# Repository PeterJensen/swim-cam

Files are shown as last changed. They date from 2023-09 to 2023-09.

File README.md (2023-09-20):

# Swim Cam

I signed up for the [Copenhagen Open Water swim](https://copenhagenswim.com/en/) around the parliament building (Christiansborg) this year (2023), and thought it would be cool to have some image/video footage from the swimmer's POV. I was also looking for a project, so two birds with one stone. It would be much simpler to use an Insta360 or GoPro with a custom mount of some sort, but that would rob me of the chance to design a system from the ground up and write a bunch of software.

## Requirements

* 1 or 2 cameras
* Simple user interface
* Waterproof enclosure (obviously)
* Access to the recorded images/videos via WiFi Access Point
* Body mount shouldn't interfere with swim stroke/speed

I picked the ESP32-CAM as the processor/camera combo. It is inexpensive (~$6) and has no availability issues. I had worked with this board before, so there would be no gotchas. The trade-off would be a less than stellar image quality.

## User Interface

The device needs three modes; a recording mode, a WiFi access mode, and an 'idle' mode. The 'idle' mode allows for cleanly finishing writes to the SDcard, to avoid corrupting it's contents, if the power is turned off in the middle of a write operation.

The solution, I settled on, uses:
1. On/Off power switch
2. Push button
3. Led to indicate current mode

After turning on the device, it will wait 10 seconds. If the user pushes the button within those 10 seconds it will go into WiFi access mode and act as a web-server. If the user does nothing it will start recording images and saving them to the SD card.  This continues until the user pushes the button again, which brings the device into 'idle' mode. It is now safe to turn off the power switch.

The LED will indicate the mode as follows:
* **Steady On**: Power is on, waiting 10 seconds for button push
* **Slow Blink Rate**: Device is taking pictures
* **Fast Blink Rate**: Device is in WiFi hotspot mode
* **Steady Off**: Device is idle and can safely be turned off.

## Enclosure

The device should be streamlined and low profile.  I had decided to use 4x AA batteries for power, so the majority of the device volume would be taken up by batteries. It's convenient to use a widely available standard size. You can get AAs anywhere. It turned out that the device can run ~16 hours on 4 rechargeables.  Much longer on regular alkalines, I'm sure.

|||
|-|-|
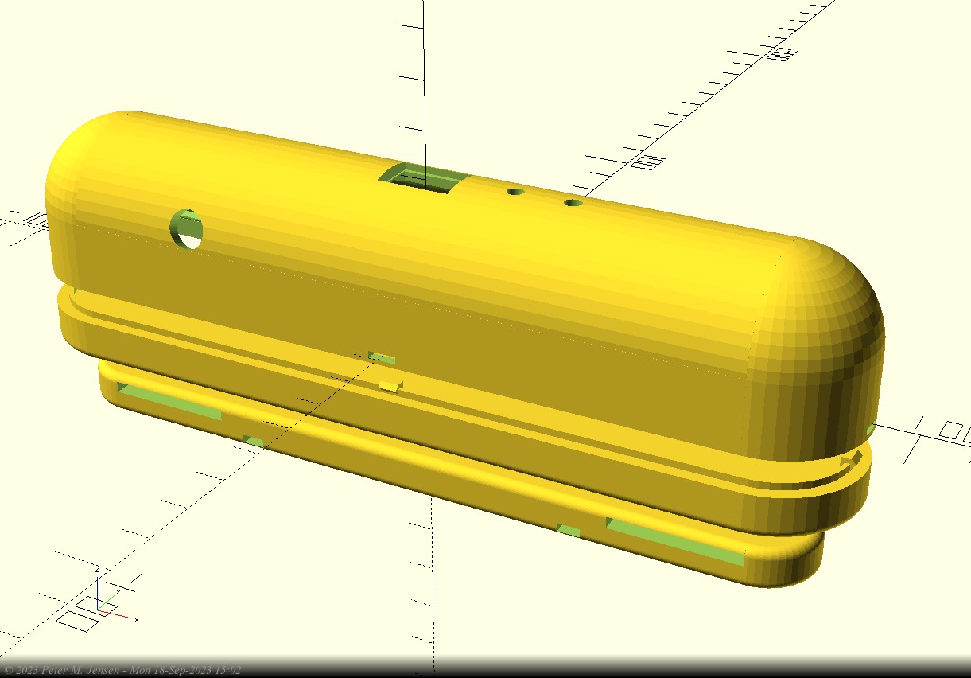
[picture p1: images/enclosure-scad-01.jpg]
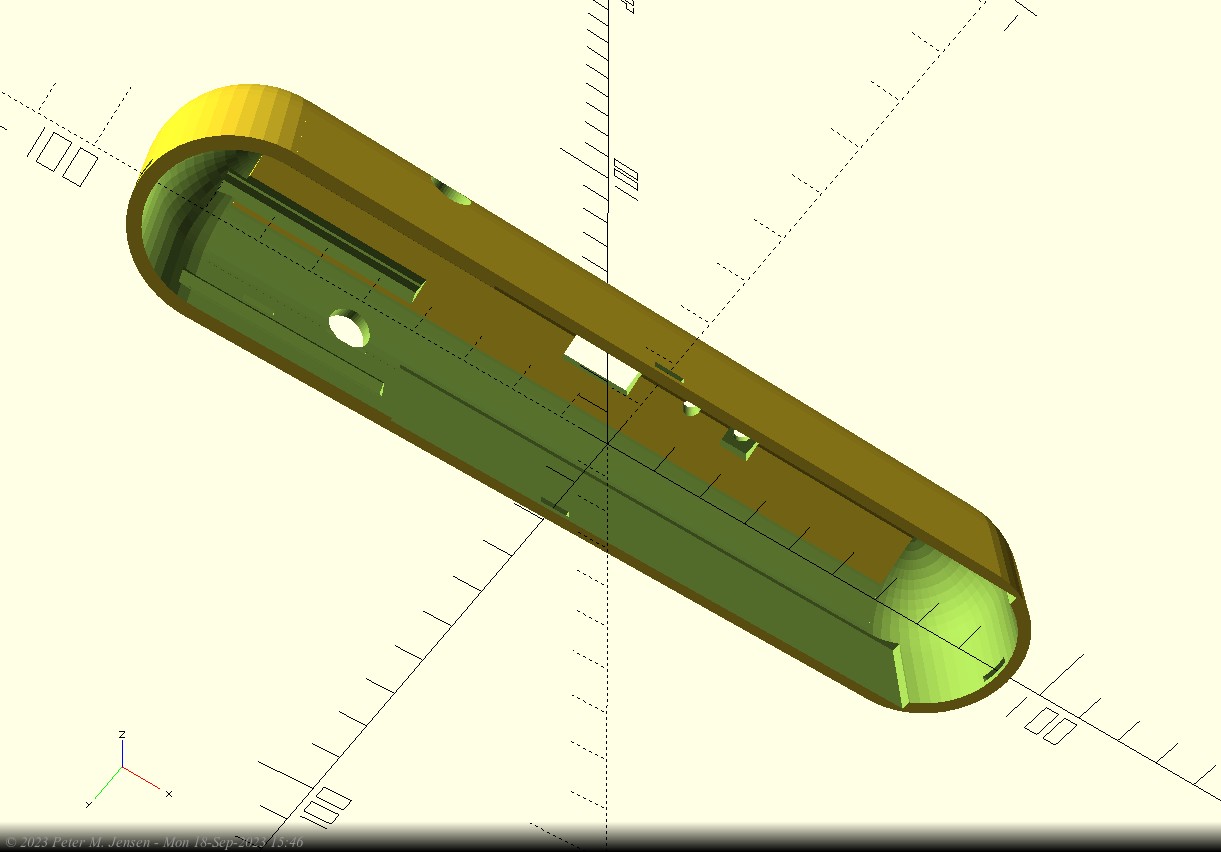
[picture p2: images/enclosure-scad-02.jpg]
|||
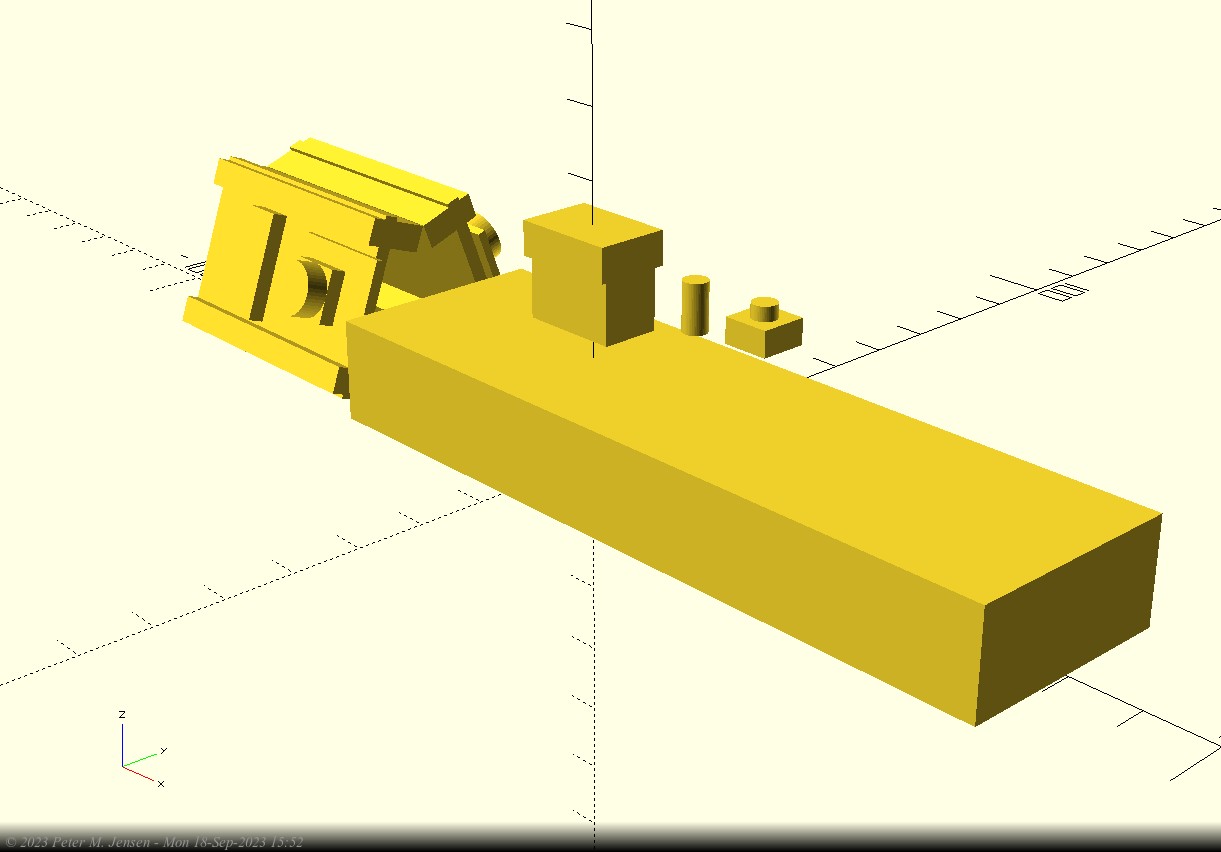
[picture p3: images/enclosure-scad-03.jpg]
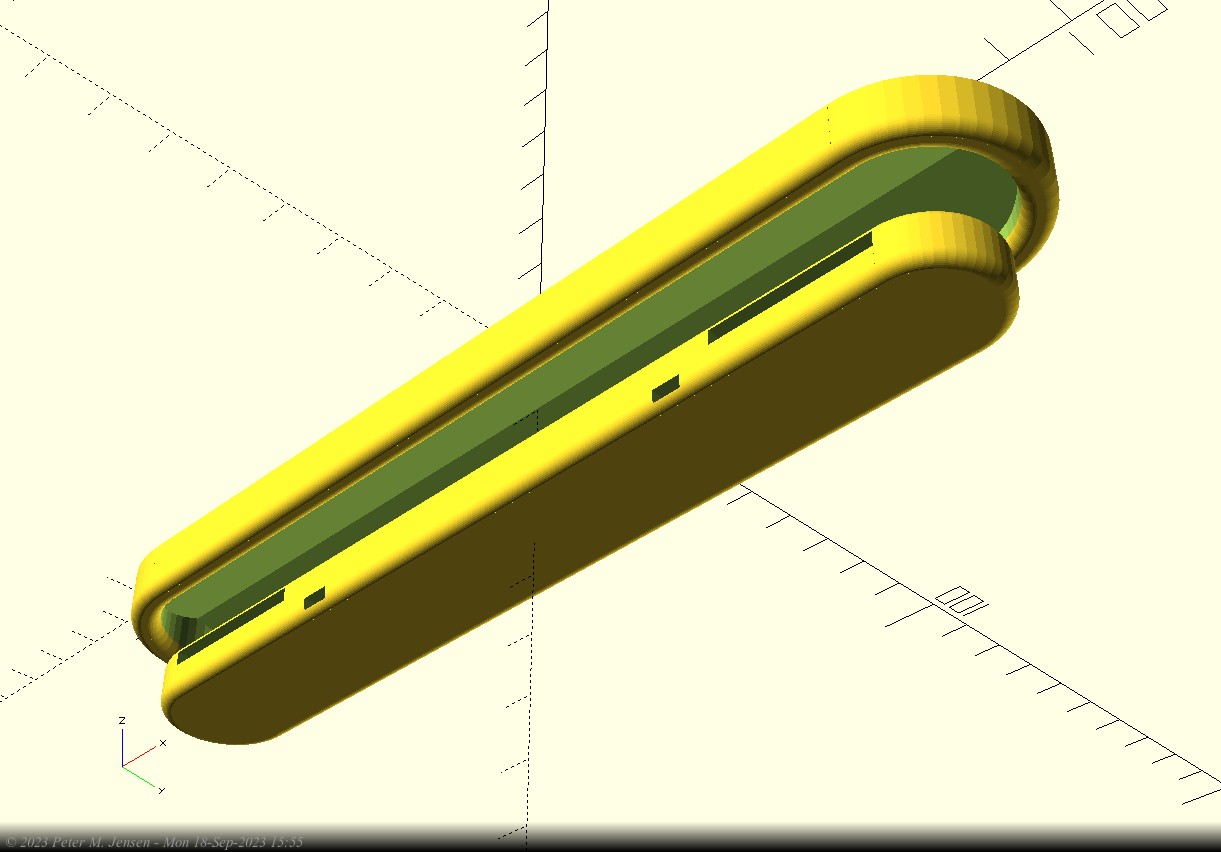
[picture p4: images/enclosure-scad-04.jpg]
|||

The enclosure consists of three separate pieces. The top part contains all the guts, the middle part is a lid for the top part. These two parts are sealed within a plastic vacuum bag.  The bottom part holds the straps and are zip tied to the top two parts. The bottom part with the straps are outside the sealed compartment.

The inside of the top part has space for two ESP32-CAM boards, and two 2xAA battery packs.

The bottom left picture shows the guts that goes inside the top part. The two slanted things to the left are two ESP32-CAM boards, the long square box is the two 2xAA battery holders. I find it useful to model the inside as well as the enclosure, so a simple difference() operation can be used to make the holes and groves in the actual enclosure. It also helps when determining the dimensions of the enclosure itself.

I used openScad for the design of the enclosure. openScad uses a scripting language, of sorts, to specify your objects. It's not much different than writing software in a regular programming language, so pretty easy to learn for a software person.

The actual device looks like this:

|||
|-|-|
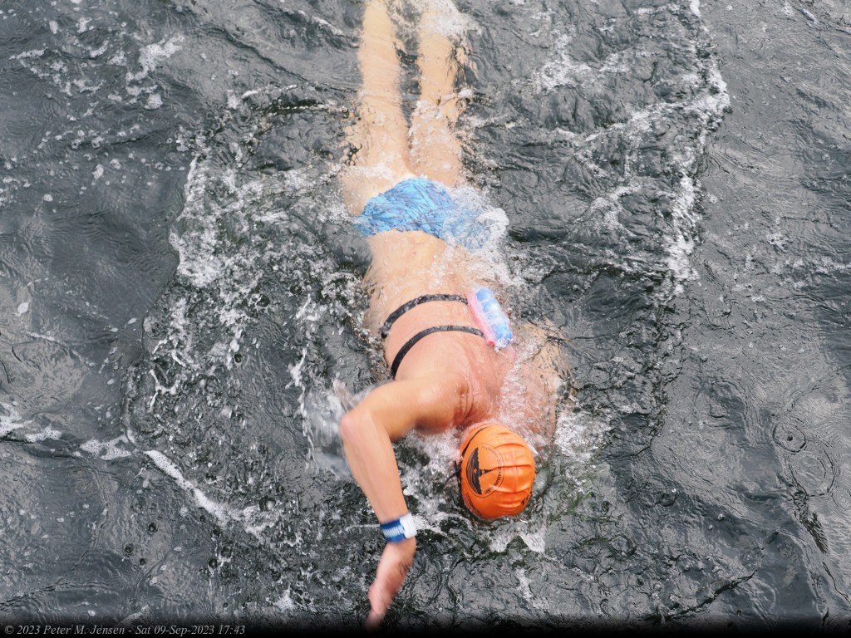
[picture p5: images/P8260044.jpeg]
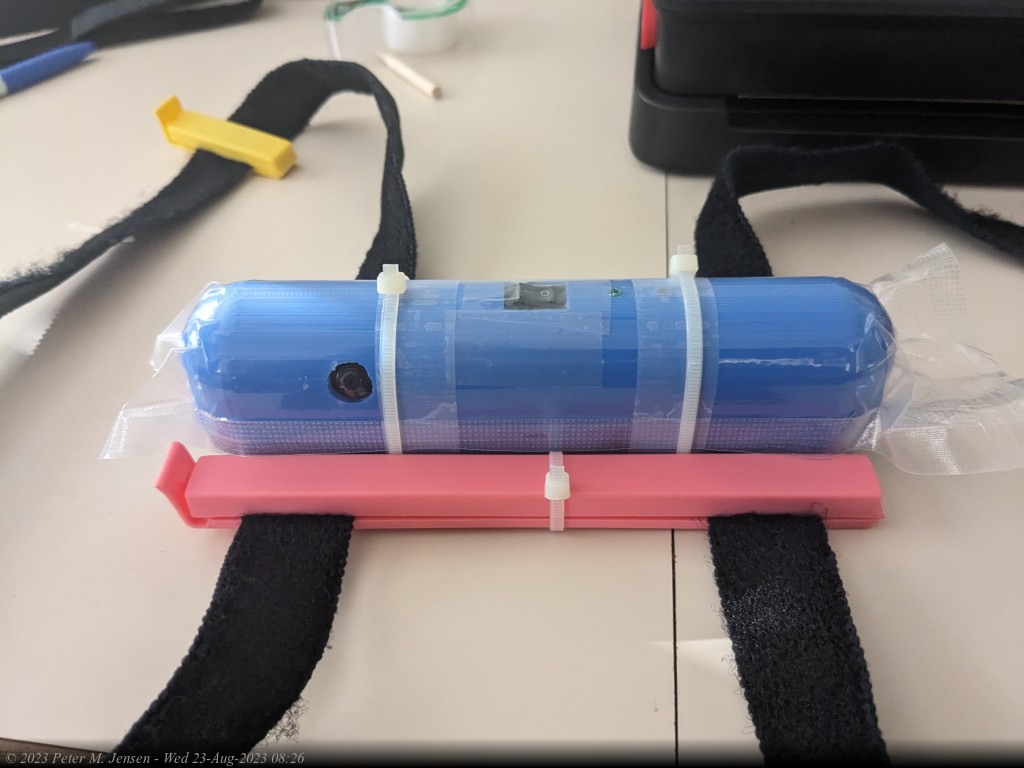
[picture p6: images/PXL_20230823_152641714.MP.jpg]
|||

The pink clips on each side are freezer bag clips. They prevent the device from sliding around.  During the 45min swim it stayed in place. The straps are velcro straps.

## ESP32-CAM

This little marvel costs about $6. For that you get:
* ESP32 MCU
* 4M PSRAM (Pseudo Static RAM). Used for frame buffers
* 2M pixel camera
* SD card slot

There's a few drawbacks though. Primarily:
* Lack of extra GPIO pins
* Processing power of the ESP32 is limiting the frame rates and sizes
* The quality of the images is less than what I would've liked
* No on-board USB/Serial chip, so an external FTD 232 device is needed. Not a big deal, and having fewer chips on the board means that less power is consumed

## Software

There are three categories of software:
* **Device**: C++ Code running on the ESP32
* **Web App**: HTML/JS single page app (SPA) for showing the images recorded on the SD card
* **Scripts for Post Processing**: A collection of Web apps and PHP scripts for extracting the good images, and presenting them as a web page

### Device Software

I used the awesome PlatformIO VS Code plugin to write this code. The project resides in the **swim-cam/** sub directory.

Images are stored on the SD card as follows:

> `GGGG/SSSS/TTTTTTTT.jpg`

**GGGG**: A 4 digit group number. Each time the device is turned on and brought into recording mode (after 10 seconds), a new group directory is created. The groups are created in sequence, i.e. 0000, 0001, 0002, etc. The highest group number holds the most recent recording.

**SSSS**: A 4 digit sub-group number. Each subgroup will hold a maximum of 100 files. The subgroups are there to prevent directories with thousands of files, since that seems to slow down access to the SD card.

**TTTTTTTT**: An 8 digit timestamp, indicating how many milli seconds have transpired since the device started recording.

### Web App Software

When the device is in WiFi hotspot mode it serves up a single page web app (SPA). The initial screen shows the available groups stored on the SD card. The last recording appears first.  After clicking on a group the images in that group can be traversed with the buttons below the image.

After connecting to the WiFi Hotspot for the camera (SWIM-CAM1), point the browser to:

> `http://192.168.4.1/`

* **>** and **<**: forward and backward one image
* **>>** and **<<**: forward and backward ten images
* **>>>** and **<<<**: forward and backward a hundred images

Here's example screenshots of the two UI screen:
|||
|-|-|
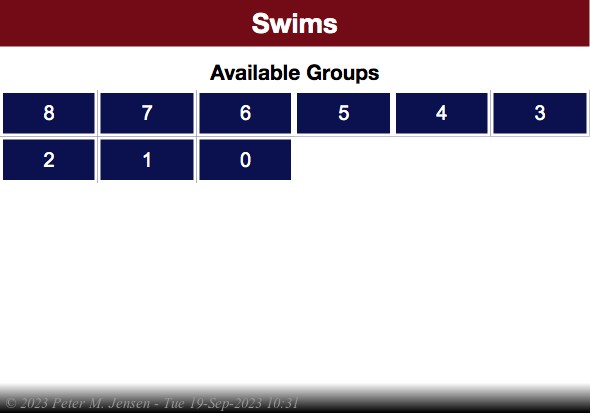
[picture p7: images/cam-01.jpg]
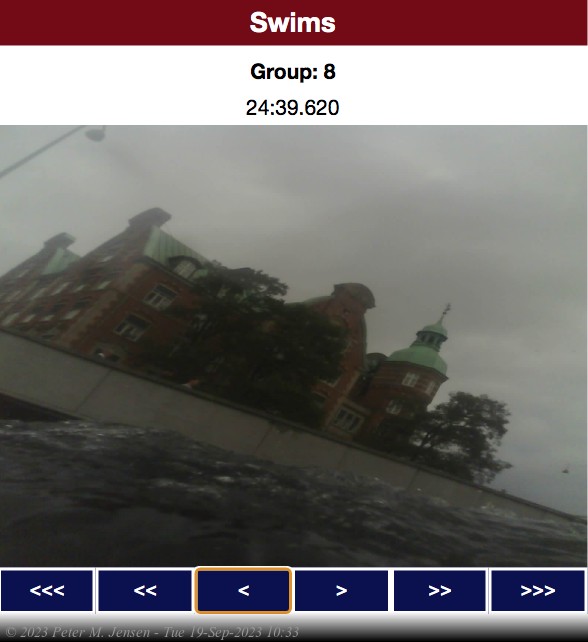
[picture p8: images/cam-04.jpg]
|||

### Scripts for Post Processing

## Actual Images from Copenhagen Swim 2023

## Post Mortem

### The Good Parts

* The enclosure didn't leak. The freezer bag vacuum packing worked like a charm
* The mounting on my back was not annoying or intrusive. I hardly noticed it. Other people did though, and it turned out to be a great conversation starter.
* User Interface and Software worked as intended. Accessing the recorded images via WiFi took a long time to initially load, when there are tens of thousands of images to show. Some re-design is needed. I had only tested it on smaller groups of images.

### The Bad Parts

* #1 issue was that very few of the in-water images had contents besides blurry images of water on them. During the 75 min of recording ~16,000 images were recorded, but only about 100 of them had contents worth looking at.
* A lot of the images weren't in focus.
* The ESP32 is only able to process (save as jpeg) about 3 full size images (1600x1200) per second. The writes to the SD card could be sped up slightly by using a 4 bit bus instead of a 1 bit one. Unfortunately, that means that there aren't enough GPIO pins available for the button and LED.

## Next Version

If I were to make a next version, I would consider:
* A better camera. Maybe the one that comes with the RaspberryPi, which is 5MP (8MP for the new one) vs. the 2MP used by the ESP32-CAM
* A more powerful CPU/Microcontroller. Probably a Raspberry Pi Pico W.
* A smaller battery. This would also make the device volume smaller. Maybe a standard 9V rechargeable instead of 4xAA.

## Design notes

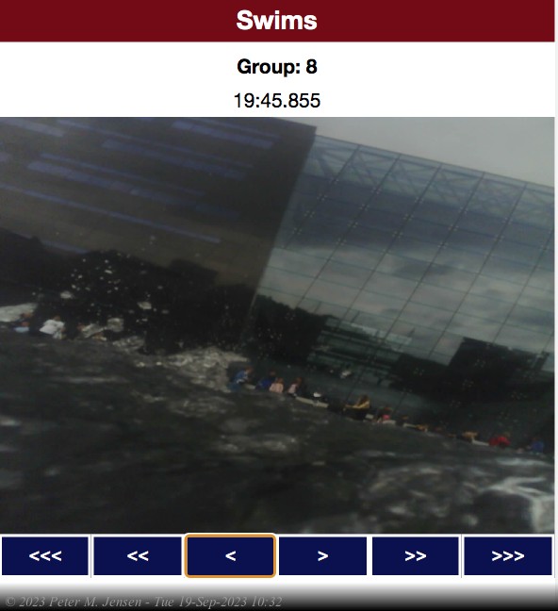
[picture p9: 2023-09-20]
images/cam-03.jpg

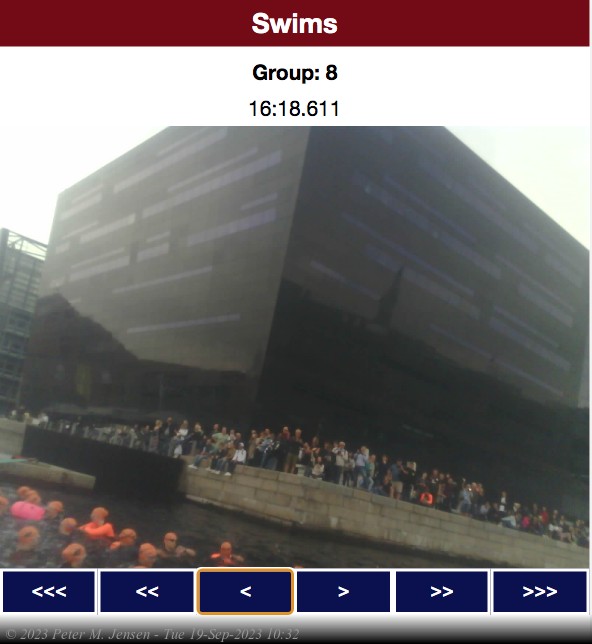
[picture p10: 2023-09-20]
images/cam-02.jpg

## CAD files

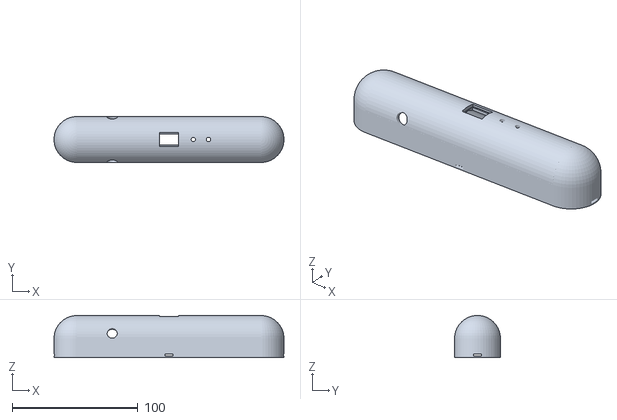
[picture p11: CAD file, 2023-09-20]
swim-cam.stl
182.9 x 36.6 x 36.6

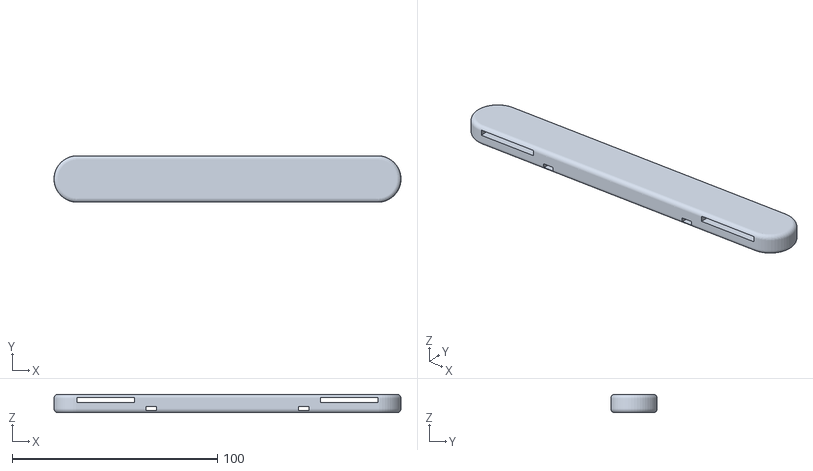
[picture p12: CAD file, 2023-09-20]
swim-cam-bar.stl
168.9 x 22.6 x 9.00

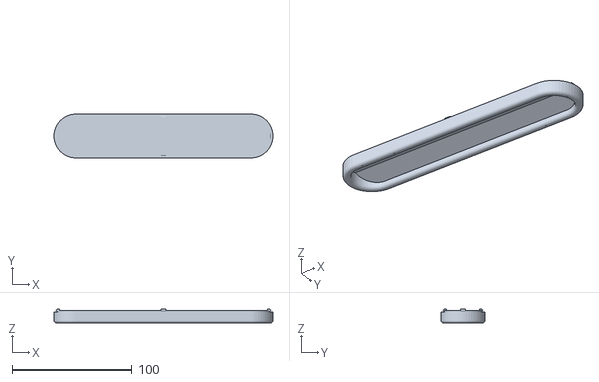
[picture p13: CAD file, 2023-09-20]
swim-cam-lid.stl
182.9 x 36.6 x 11.5

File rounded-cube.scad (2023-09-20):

// Author: Peter Jensen

module roundCut(dims, r) {
  difference() {
    translate([-1, -1, -dims.z/2-0.5])
      cube([r+1, r+1, dims.z+1]);
    translate([r, r, 0])
      cylinder(h = dims.z+1.5, r = r, center = true);
  }
}

module pillCylinder(h, r) {
  cylinder(h = h-2*r, r = r, center=true);
  translate([0, 0, h/2-r]) sphere(r = r);
  translate([0, 0, -h/2+r]) sphere(r = r);
}
  
module roundCut2(dims, r) {
  difference() {
    translate([-1, -1, -dims.z/2-0.5])
      cube([r+1, r+1, dims.z+1]);
    translate([r, r, 0])
      pillCylinder(h = dims.z, r = r);
  }
}

module cornerCut(r) {
  difference() {
    cube([r, r, r], center = true);
    translate([r/2, r/2, r/2]) sphere(r=r);
  }
}

module cornerCut4(dims, r) {
  translate([(dims.x-r)/2, (r-dims.y)/2, (dims.z-r)/2]) rotate([-90, 0, 90]) cornerCut(r);
  translate([(dims.x-r)/2, (r-dims.y)/2, (r-dims.z)/2]) rotate([0, 0, 90]) cornerCut(r);
  translate([(dims.x-r)/2, (dims.y-r)/2, (dims.z-r)/2]) rotate([-90, 0, 180]) cornerCut(r);
  translate([(dims.x-r)/2, (dims.y-r)/2, (r-dims.z)/2]) rotate([0, 0, -180]) cornerCut(r);
}  

module roundCuts(dims, edges, r) {
  echo ("roundCuts");
  if (abs(edges) != undef) {  
    translate([-dims.x/2, -dims.y/2, 0]) roundCut(dims, r);
    translate([dims.x/2, dims.y/2, 0]) rotate([0, 0, 180]) roundCut(dims, r);
    translate([dims.x/2, -dims.y/2, 0]) rotate([0, 0, 90]) roundCut(dims, r);
    translate([-dims.x/2, dims.y/2, 0]) rotate([0, 0, -90]) roundCut(dims, r);
  }
  else {
    if (edges[0]) translate([-dims.x/2, -dims.y/2, 0]) roundCut(dims, r);
    if (edges[2]) translate([dims.x/2, dims.y/2, 0]) rotate([0, 0, 180]) roundCut(dims, r);
    if (edges[1]) translate([dims.x/2, -dims.y/2, 0]) rotate([0, 0, 90]) roundCut(dims, r);
    if (edges[3]) translate([-dims.x/2, dims.y/2, 0]) rotate([0, 0, -90]) roundCut(dims, r);
  }
}

module roundedCube(dims, r, axis=[1, 1, 1]) {
  difference() {
    cube(dims, center = true);
    if (axis.x)
      rotate([0, 90, 0]) roundCuts([dims.z, dims.y, dims.x], axis.x, r);
    if (axis.y)
      rotate([90, 0, 0]) roundCuts([dims.x, dims.z, dims.y], axis.y, r);
    if (axis.z)
      roundCuts(dims, axis.z, r);
    if (axis.x && axis.y && axis.z) {
      cornerCut4(dims, r);
      rotate([0, 0, 180]) cornerCut4(dims, r);
    }
  }
}

//$fn=40;
//dims=[20,30,40];
//r = 3;

//cornerCut(dims, r);
//translate([-dims.x/2, -dims.y/2, 0]) 
//  roundCut2(dims, r);
//roundCuts(dims, 1, r);

//difference() {
//  roundedCube(dims, r, axis=[1,1,1]);
//  cornerCut4(dims, r);
//  rotate([0, 0, 180]) cornerCut4(dims, r);
//}

//pillCylinder(dims.z, r);
//cylinder(h = dims.z-2*r, r = 5, center=true);
//translate([0, 0, dims.z/2-r]) sphere(r = 5);
//translate([0, 0, -dims.z/2+r]) sphere(r = 5);

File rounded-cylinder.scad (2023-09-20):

// Author: Peter Jensen

module cutBox(d, r) {
  difference() {
    translate([0, 0, -(r)/2])
      cube([d, d, r], center = true);
    rotate_extrude() {
      translate([d/2-r, 0]) circle(r = r);
      translate([0, -r]) square([d/2-r, 2*r]);
    }
  }
}

module cutBoxRing(d, r, t) {
  difference() {
    translate([0, 0, -(r)/2])
      cube([d, d, r], center = true);
    rotate_extrude() {
      translate([d/2-r, 0]) circle(r = r);
      translate([d/2-t+r, 0]) circle(r = r);
      translate([d/2-t+r, -r]) square([t-2*r, 2*r]);
    }
  }
}
  
module roundedCylinder(d, h, r) {
  difference() {
    cylinder(d = d, h = h, center = true);
    if (r != -1)
      translate([0, 0, -h/2+r])
        cutBox(d, r);
  }
}

module roundedRing(d, h, r, t) {
  difference() {
    cylinder(d = d, h = h, center=true);
    cylinder(d = d - 2*t, h = h, center=true);
    if (r != -1)
      translate([0, 0, -h/2+r])
        cutBoxRing(d, r, t);
  }
}

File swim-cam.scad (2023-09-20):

// Author: Peter Jensen

$fn = 50;

include <rounded-cube.scad>
include <rounded-cylinder.scad>

// Dimensions

x = 0; y = 1; z = 2;

m = 0.2;

batteryDims   = [56.7+m, 32.4+m, 15.0];
//esp32Dims   = [27.1, 39.8, 1.9];
esp32Dims     = [39.8+m, 27.1+m, 1.9+m];
//esp32PinsDims = [20.0, 2.4, 8.0];
//esp32PinsDims = [20.0, 4.0, 8.0];
esp32PinsDims = [esp32Dims[x], 4.0, 9.0];
esp32SdDims   = [17.2+m, 14.6+m, 1.3];
//esp32CamDims  = [8.0+m, 8.0+m, 2.1];
esp32CamDims  = [8.0+m, 8.0+m, 2.4];
esp32CamD     = 8.0+m;
esp32CamZ     = 3.4;
//esp32CamConnDims = [5.8, 16.3, 1.9];
esp32CamConnDims = [6.0, 16.5, 2.5];

tapDims       = [4.0, 6.0, 1.5];
tapOffset     = 1.0;
switchInnerD  = 12.0;
//switchOuterD  = 13.9;
switchOuterD  = 16.0;
switchInnerZ  = 23.9;
switchOuterZ  = 7.0;
switchZ       = switchInnerZ + switchOuterZ;

esp32SdSpace  = 2.5;
shellX        = 2*batteryDims.x + esp32Dims.x + esp32SdSpace - 10.0;
shellD        = batteryDims.y + 4.0;
shellT        = 2.5;
shellXOffset  = -esp32SdSpace/2;
shellXOffset  = 0;
shellZOffset  = batteryDims.z-2;

shellRoofDims = [shellX, shellD/2 - 5.0, 2.0];
shellRoofTilt = 20;

shiftX = -3.5;
battery1Offsets   = [(batteryDims.x-shellX)/2+esp32Dims.x + esp32SdSpace + shiftX, 0, batteryDims[z]/2];
battery2Offsets   = [battery1Offsets.x + batteryDims.x, 0, batteryDims[z]/2];
esp32Tilt         = 20;
esp32LOffsets     = [(esp32Dims.x - shellX)/2 + shiftX, ( sin(esp32Tilt)-1)*batteryDims[y]/2+0.5, esp32Dims[y]/2+1];
esp32ROffsets     = [(esp32Dims.x - shellX)/2 + shiftX, (-sin(esp32Tilt)+1)*batteryDims[y]/2-0.5, esp32Dims[y]/2+1];
//esp32Pins1Offsets = [-(esp32Dims[x]-esp32PinsDims[x])/2+2.7, -(esp32Dims[y]-esp32PinsDims[y])/2+0.6, (esp32Dims[z]-esp32PinsDims[z])/2 + 0.9];
esp32Pins1Offsets = [0, -(esp32Dims[y]-esp32PinsDims[y])/2+0.6, (-esp32Dims[z]+esp32PinsDims[z])/2 - 5.0];
esp32Pins2Offsets = [esp32Pins1Offsets[x], -esp32Pins1Offsets[y], esp32Pins1Offsets[z]];
esp32SdOffsets    = [(esp32SdDims[x]-esp32Dims[x])/2-1.9, 0, (esp32Dims[z]+esp32SdDims[z])/2];
esp32CamOffsets   = [(esp32CamDims[x]-esp32Dims[x])/2+4.4, 0, (esp32CamDims[z]+esp32Dims[z])/2 + esp32SdDims[z]];


module battery1() {
  translate(battery1Offsets)
    cube(batteryDims, center = true);
}

module battery2() {
  translate(battery2Offsets)
    cube(batteryDims, center = true);
}

module esp32Cam() {
  cube(esp32CamDims, center = true);
  translate([0, 0, esp32CamDims[z]/2])
    cylinder(d = esp32CamD, h = esp32CamZ);
}
  
module esp32Base() {
  translate(esp32Pins1Offsets)
    cube(esp32PinsDims, center = true);
  translate(esp32Pins2Offsets)
    cube(esp32PinsDims, center = true);
  translate(esp32SdOffsets)
    cube(esp32SdDims, center = true);
  translate(esp32CamOffsets)
    esp32Cam();
  cube(esp32Dims, center = true);
  translate([(esp32Dims[x] - esp32CamConnDims[x])/2 - 11.5, 0, (esp32CamConnDims[z] + esp32Dims[z])/2])
    cube(esp32CamConnDims, center = true);
}

module esp32L() {
  translate(esp32LOffsets)
    rotate([-90-esp32Tilt, 0, 0])
      rotate([0, 180, 0])
        esp32Base();
}

module esp32R() {
  translate(esp32ROffsets)
    rotate([90+esp32Tilt, 0, 0])
      rotate([0, 180, 0])
        esp32Base();
}

module switchBase() {
  cylinder(d = switchInnerD, h = switchInnerZ);
  translate([0, 0, switchInnerZ])
    cylinder(d = switchOuterD, h = switchOuterZ);
}

module switch1() {
  translate([12.0, 0, 5.0])
    switchBase();
}

sm = 0.4;
switch2Dims = [6.3+sm, 6.3+sm, 3.6];
switch2D    = 3.5;
switch2Z    = 2.0;

switchSpacing = 12.0;

module switch2() {
//  translate([27.0, 0, 28.0]) {
  translate([onOffSwitchDims.x/2 + 2*switchSpacing, 0, 28.0]) {
    cube(switch2Dims, center = true);
    translate([0, 0, switch2Dims[z]/2])
      cylinder(d = switch2D, h = switch2Z);
  }
}
  
module switch2a() {
  translate([(shellX + shellD - switchZ)/2 - 0.0, 0, 22])
    rotate([0, 85, 0])
      translate([0, 0, -switchZ/2])
        switchBase();
}

module inside() {
  battery1();
  battery2();
  esp32L();
  esp32R();
  //switch1();
  switch2();
  onOffSwitch();
  led();
//  esp32Base();
}

module shellCyl() {
  difference() {
    rotate([0, 90, 0])
      translate([0, 0, -shellX/2])
        difference() {
          cylinder(d = shellD, h = shellX);
          cylinder(d = shellD-2*shellT, h = shellX);
        };
    translate([0, 0, -shellD/4])
      cube([shellX+1, shellD, shellD/2], center = true);
  }
}

module shellSphere() {
  difference() {
    sphere(d = shellD);
    sphere(d = shellD-2*shellT);
    translate([shellD/2, 0, 0])
      cube(shellD, center = true);
    translate([0, 0, -shellD/2])
      cube(shellD, center = true);
  }
}
  
module shellTop() {
  shellCyl();
  translate([-shellX/2, 0, 0])
    shellSphere();
  translate([shellX/2, 0, 0])
    rotate([0, 0, 180])
      shellSphere();
  translate([0, 0, shellD/2-7])
    shellRoof(shellRoofDims);
}

module shellCap() {
  translate([0, 0, -batteryDims[z]/2])
    difference() {
      cylinder(d = shellD, h = batteryDims[z]);
      cylinder(d = shellD - 2*shellT, h = batteryDims[z]);
      translate([shellD/2, 0, batteryDims[z]/2])
        cube([shellD, shellD, batteryDims[z]], center = true);
      translate([(tapDims[x]-shellD)/2, 0, tapDims[z]/2 + tapOffset])
        cube(tapDims, center = true);
    }
}

shellBottomOffsets = [0, 0, -batteryDims[z]/2];

module shellBottom() {
  translate(shellBottomOffsets) {
    difference() {
      cube([shellX, shellD, batteryDims[z]], center = true);
      cube([shellX, shellD - 2*shellT, batteryDims[z]], center = true);
      translate([0, (shellD - tapDims[x])/2, (tapDims[z] - batteryDims[z])/2 + tapOffset])
        rotate([0, 0, 90])
          cube(tapDims, center = true);
      translate([0, (-shellD + tapDims[x])/2, (tapDims[z] - batteryDims[z])/2 + tapOffset])
        rotate([0, 0, 90])
          cube(tapDims, center = true);
    }
    translate([-shellX/2, 0, 0])
      shellCap();
    translate([shellX/2, 0, 0])
      rotate([0, 0, 180])
        shellCap();
  }
}

module shellRoof(dims) {
  yOffset = cos(shellRoofTilt)*dims.y/2 - sin(shellRoofTilt)*dims.z/2;
  zOffset = sin(shellRoofTilt)*dims.y/2 + dims.z/2;
  translate([0, -yOffset, zOffset])
    rotate([shellRoofTilt, 0, 0])
      cube(dims, center = true);
  translate([0, yOffset, zOffset])
    rotate([-shellRoofTilt, 0, 0])
      cube(dims, center = true);
}

module shell() {
  difference() {
    translate([shellXOffset, 0, shellZOffset]) {
      shellTop();
      shellBottom();
    }
    inside();
    translate([0, 0, -batteryDims[z]])
      battery1();
    translate([0, 0, -batteryDims[z]])
      battery2();
  }
}

shellBaseDims = [shellX, shellD, 5.0];

module shellBaseShape(dims, r = -1) {
  cube(dims, center = true);
  translate([dims[x]/2, 0, 0])
    roundedCylinder(d = dims[y], h = dims[z], r = r);
  translate([-dims[x]/2, 0, 0])
    roundedCylinder(d = dims[y], h = dims[z], r = r);
}

shellBaseRimT = 1.0;

module shellBaseRimShape(dims) {
  difference() {
    shellBaseShape(dims);
    shellBaseShape([dims.x, dims.y-2*shellBaseRimT, dims.z]);
  }
}

shellBaseRimDims = [shellBaseDims[x]-0.2, shellBaseDims[y]-2*shellT-0.2, 1.5];

module shellBaseRim() {
  translate([0, 0, shellBaseRimDims[z]/2 + shellBaseDims[z]/2])
    shellBaseRimShape(shellBaseRimDims);
}

magnetD = 16.4;
magnetZ = 5.2;

module magnet() {
  cylinder(d = magnetD, h = magnetZ, center = true);
}

module magnets() {
  qx = (shellX+shellD)/16;
  translate([-6.0*qx, 0, 0])
    magnet();
  translate([-1.5*qx, 0, 0])
    magnet();
  translate([1.5*qx, 0, 0])
    magnet();
  translate([6.0*qx, 0, 0])
    magnet();
}

shellRailDims = [shellX, 5.0, shellBaseDims.z + 4.0];
//railCutDims = [shellBaseDims.x+shellD, shellBaseDims.y - 2*shellRailDims.y, shellRailDims.z];
railCutDims = [shellBaseDims.x+shellD, shellBaseDims.y - 2*shellRailDims.y, shellRailDims.z];
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

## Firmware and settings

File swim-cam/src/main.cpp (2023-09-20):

// Author: Peter Jensen

#include <Arduino.h>
#include <FS.h>
#include <SD_MMC.h>
#include <WiFi.h>
#include <driver/sdmmc_host.h>
#include <esp_heap_caps.h>
#include <soc/rtc_wdt.h>
#include "debug.h"
#include "camera.h"
#include "sdcard.h"
#include "web-ui-server.h"

struct Config {
  static constexpr const char *imageRootDir    = "/swims";
  static const uint32_t        startupDelay    = 10000;
  static constexpr const char *ssidAp          = "SWIM-CAM1";
  static constexpr const char *ipAddrAp        = "192.168.4.1";
  static const bool            setupAp         = true;
  static constexpr const char *ssidSta         = "<YOUR-SSID>";
  static constexpr const char *passwordSta     = "<YOUR-WIFI-PASSWORD>";
};

struct Pins {
  static const uint8_t pushButton = GPIO_NUM_13;
  static const uint8_t led        = GPIO_NUM_12;
  static const uint8_t ledFlash   = GPIO_NUM_4;
};

// ---------------------------------------------------------------------------
class Led {
private:
  bool       isOn;
  uint32_t   blinkRate;
  uint32_t   lastFlip;
  uint8_t    pin;
public:
  Led() : isOn(false), blinkRate(0) {}
  void init(uint8_t _pin) {
    lastFlip = millis();
    pin = _pin;
    pinMode(pin, OUTPUT);
    off();
  }
  void setBlinkRate(uint32_t rate) {
    blinkRate = rate;
  }
  void on() {
    digitalWrite(pin, HIGH);
    isOn = true;
  }
  void off() {
    digitalWrite(pin, LOW);
    isOn = false;
  }
  void flip() {
    if (isOn)
      off();
    else
      on();
    lastFlip = millis();
  }
  void update() {
    if (blinkRate > 0 && millis() > lastFlip + blinkRate)
      flip();
  }
};

// ---------------------------------------------------------------------------
class Button {
  void     (*onClickHandler)();
  uint32_t   bounceStart;
  uint8_t    pin;
  uint8_t    lastVal;
  bool       bouncing;
public:
  void init(uint8_t _pin) {
    lastVal    = HIGH;
    bouncing   = false;
    onClickHandler = nullptr;
    pin = _pin;
    pinMode(pin, INPUT_PULLUP);
  }
  void onClick(void (*handler)()) {
    onClickHandler = handler;
  }
  void update() {
    uint32_t now = millis();
    uint8_t  val = digitalRead(pin);
    if (!bouncing) {
      if (val != lastVal) {
        if (onClickHandler != nullptr && val == LOW) {
          onClickHandler();
        }
        lastVal = val;
        bounceStart = now;
        bouncing = true;
      }
    }
    else {
      if (now > bounceStart + 100) {
        bouncing = false;
      }
    }
  }
};

// ---------------------------------------------------------------------------
class State {
public:
  enum stateValue {takingPhotos, wifiHotspot, startup, idle};
  stateValue value;
private:
  uint32_t startTime;
public:
  State() : value(startup) {}
  void init() {
    startTime = millis();
  }
  bool updateTime() {
    if (value == startup) {
      uint32_t now = millis();
      if (now - startTime > Config::startupDelay) {
        value = takingPhotos;
        return true;
      }
    }
    return false;
  }
  bool updateClick() {
    if (value == startup) {
      value = wifiHotspot;
      return true;
    }
    else if (value == takingPhotos || value == wifiHotspot) {
      value = idle;
      return true;
    }
    return false;
  }
};

class Images {
  const uint32_t maxImagesInSubGroup = 100;

  String    rootDir;
  SdCard   &storage;
  String    groupDir;
  uint32_t  subGroupCount;
  String    subGroupDir;
  uint32_t  imagesInSubGroup;

  static String formatGroupDir(uint32_t num) {
    char buf[100];
    sprintf(buf, "%04d", num);
    return String(buf);
  }
  static String formatSubGroupDir(uint32_t num) {
    return formatGroupDir(num);
  }
  static String formatImageFile(uint32_t timestamp) {
    char buf[100];
    sprintf(buf, "%08d.jpg", timestamp);
    return String(buf);
  }
  static uint32_t groupDirCount;
  static void walk(const char *name, bool isDir, uint32_t size) {
    groupDirCount++;
  }
  String makeNextGroupDir() {
    groupDirCount = 0;
    storage.walkDir(rootDir, 1, walk, false);
    String nextGroupDir = rootDir + "/" + formatGroupDir(groupDirCount);
    storage.createDir(nextGroupDir);
    return nextGroupDir;
  }
  String makeSubGroupDir() {
    String nextSubGroupDir = groupDir + "/" + formatSubGroupDir(subGroupCount);
    subGroupCount += 1;
    storage.createDir(nextSubGroupDir);
    return nextSubGroupDir;
  }
public:
  Images(String rootDir, SdCard &sdCard) : rootDir(rootDir), storage(sdCard) {}
  void init() {
    subGroupCount = 0;
    groupDir = makeNextGroupDir();
    subGroupDir = makeSubGroupDir();
    imagesInSubGroup = 0;
  }  
  void addImage(uint32_t timeStamp, uint8_t *data, uint32_t dataLen) {
    if (imagesInSubGroup >= maxImagesInSubGroup) {
      subGroupDir = makeSubGroupDir();
      imagesInSubGroup = 0;
    }
    String imageFile = subGroupDir + "/" + formatImageFile(timeStamp);
    storage.createFile(imageFile, data, dataLen);
    imagesInSubGroup += 1;
  }
};
uint32_t Images::groupDirCount;

Button      button;
State       state;
SdCard      sdCard(SD_MMC);
Led         led;
Images      images(Config::imageRootDir, sdCard);
Camera      camera;
WebUiServer server(sdCard, Config::imageRootDir);

void removeZeroSize(const char *name, bool isDir, uint32_t size) {
  if (!isDir && size == 0) {
    DEBUG_PRINTF("Removing: %s\n", name);
    sdCard.removeFile(name);
  }
}

void updateLed() {
  switch (state.value) {
    case State::startup:
      led.setBlinkRate(0);
      led.on();
      break;
    case State::takingPhotos:
      led.setBlinkRate(500);
      break;
    case State::wifiHotspot:
      led.setBlinkRate(100);
      break;
    case State::idle:
      led.setBlinkRate(0);
      led.off();
      break;
  }
}

void click() {
  DEBUG_PRINTF("Button Clicked\n");
  bool change = state.updateClick();
  if (change) {
    DEBUG_PRINTF("New state after updateClick: %d\n", state.value);
    updateLed();
  }
}

void setup() {
  DEBUG_INIT();
  WRITE_PERI_REG(RTC_CNTL_BROWN_OUT_REG, 0);
  pinMode(Pins::ledFlash, OUTPUT);
  digitalWrite(Pins::ledFlash, LOW);
  led.init(Pins::led);
  led.on();
  button.init(Pins::pushButton);
  button.onClick(click);
  state.init();
}

uint32_t firstCaptureTime;
bool     hasFinishedCapturing = false;
bool     serverStarted        = false;
bool     serverStopped        = false;

void loop() {
  led.update();
  button.update();
  bool change = state.updateTime();
  if (change) {
    DEBUG_PRINTF("New state after updateTime: %d\n", state.value);
    updateLed();
  }
  switch (state.value) {
    case State::startup:
      break;
    case State::takingPhotos: {
      if (change) {
        camera.init();
        camera.dumpStatus();
        sdCard.begin();
        images.init();
        firstCaptureTime = millis();
      }
      uint8_t *buf;
      uint32_t len;
      uint32_t captureTime = millis();
      camera.capture(&buf, &len);
      images.addImage(captureTime - firstCaptureTime, buf, len);
      camera.captureRelease();
      break;
    }
    case State::wifiHotspot:
      if (!serverStarted) {
        if (Config::setupAp) {
          IPAddress ipAddr;
          ipAddr.fromString(Config::ipAddrAp);
          serverStarted = server.startAp(Config::ssidAp, ipAddr);
        }
        else
          serverStarted = server.startSta(Config::ssidSta, Config::passwordSta);
        server.startServer();
      }
      break;
    case State::idle:
      if (!hasFinishedCapturing) {
        //sdCard.walkDir(Config::imageRootDir, 3);
        sdCard.end();
        hasFinishedCapturing = true;
      }
      if (!serverStopped && serverStarted) {
        server.stopServer();
        serverStopped = true;
      }
      break;
  }
}

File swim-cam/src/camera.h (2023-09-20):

// Author: Peter Jensen

#ifndef _CAMERA_H
#define _CAMERA_H
#include <esp_camera.h>
#include "debug.h"

#define PWDN_GPIO_NUM     32
#define RESET_GPIO_NUM    -1
#define XCLK_GPIO_NUM      0
#define SIOD_GPIO_NUM     26
#define SIOC_GPIO_NUM     27

#define Y9_GPIO_NUM       35
#define Y8_GPIO_NUM       34
#define Y7_GPIO_NUM       39
#define Y6_GPIO_NUM       36
#define Y5_GPIO_NUM       21
#define Y4_GPIO_NUM       19
#define Y3_GPIO_NUM       18
#define Y2_GPIO_NUM        5
#define VSYNC_GPIO_NUM    25
#define HREF_GPIO_NUM     23
#define PCLK_GPIO_NUM     22

#define LED_GPIO_NUM      4

static camera_config_t cameraConfig = {
  .pin_pwdn = PWDN_GPIO_NUM,
  .pin_reset = RESET_GPIO_NUM,
  .pin_xclk = XCLK_GPIO_NUM,
  .pin_sccb_sda = SIOD_GPIO_NUM,
  .pin_sccb_scl = SIOC_GPIO_NUM,
  .pin_d7 = Y9_GPIO_NUM,
  .pin_d6 = Y8_GPIO_NUM,
  .pin_d5 = Y7_GPIO_NUM,
  .pin_d4 = Y6_GPIO_NUM,
  .pin_d3 = Y5_GPIO_NUM,
  .pin_d2 = Y4_GPIO_NUM,
  .pin_d1 = Y3_GPIO_NUM,
  .pin_d0 = Y2_GPIO_NUM,
  .pin_vsync = VSYNC_GPIO_NUM,
  .pin_href = HREF_GPIO_NUM,
  .pin_pclk = PCLK_GPIO_NUM,
  .xclk_freq_hz = 20000000,
  .ledc_timer = LEDC_TIMER_0,
  .ledc_channel = LEDC_CHANNEL_0,
  .pixel_format = PIXFORMAT_JPEG,
  .frame_size = FRAMESIZE_UXGA,
  .jpeg_quality = 10,
  .fb_count = 2,
  .fb_location = CAMERA_FB_IN_PSRAM,
  .grab_mode = CAMERA_GRAB_LATEST,
  .sccb_i2c_port = -1 // Not used because pin_sccb_sda != -1
};

class Camera {
  camera_fb_t *fb = nullptr;
public:
  bool init() {
    esp_err_t err = esp_camera_init(&cameraConfig);
    if (err != ESP_OK) {
      DEBUG_PRINTF("Camera: Init failed with error 0x%x\n", err);
      return false;
    }
    sensor_t *s = esp_camera_sensor_get();
    s->set_aec2(s, 1);
    pinMode(LED_GPIO_NUM, OUTPUT);
    digitalWrite(LED_GPIO_NUM, LOW);

    // warm up the camera
    uint8_t  *buf;
    uint32_t  len;
    for (uint32_t i = 0; i < 5; i++) {
      capture(&buf, &len);
      captureRelease();
    }
    delay(1000);
    for (uint32_t i = 0; i < 5; i++) {
      capture(&buf, &len);
      captureRelease();
    }
    return true;
  }
  bool capture(uint8_t **buf, uint32_t *len) {
    if (fb != nullptr) {
      DEBUG_PRINTF("Camera: Last capture not released\n");
      return false;
    }
    fb  = esp_camera_fb_get();
    if (!fb) {
      DEBUG_PRINTF("Camera: Capture fail\n");
      return false;
    }
    *buf = fb->buf;
    *len = fb->len;
    return true;
  }

  void captureRelease() {
    esp_camera_fb_return(fb);
    fb = nullptr;
  }

  void dumpStatus() {
    sensor_t        *s = esp_camera_sensor_get();
    camera_status_t *status = &(s->status);
    DEBUG_PRINTF("xclk:           %u\n", s->xclk_freq_hz/1000000);
    DEBUG_PRINTF("pixformat:      %u\n", s->pixformat);
    DEBUG_PRINTF("framesize:      %u\n", status->framesize);
    DEBUG_PRINTF("quality:        %u\n", status->quality);
    DEBUG_PRINTF("brightness:     %d\n", status->brightness);
    DEBUG_PRINTF("contrast:       %d\n", status->contrast);
    DEBUG_PRINTF("saturation:     %d\n", status->saturation);
    DEBUG_PRINTF("sharpness:      %d\n", status->sharpness);
    DEBUG_PRINTF("special_effect: %u\n", status->special_effect);
    DEBUG_PRINTF("wb_mode:        %u\n", status->wb_mode);
    DEBUG_PRINTF("awb:            %u\n", status->awb);
    DEBUG_PRINTF("awb_gain:       %u\n", status->awb_gain);
    DEBUG_PRINTF("aec:            %u\n", status->aec);
    DEBUG_PRINTF("aec2:           %u\n", status->aec2);
    DEBUG_PRINTF("aec_value:      %u\n", status->aec_value);
    DEBUG_PRINTF("agc:            %u\n", status->agc);
    DEBUG_PRINTF("agc_gain:       %u\n", status->agc_gain);
    DEBUG_PRINTF("gainceiling:    %u\n", status->gainceiling);
    DEBUG_PRINTF("bpc:            %u\n", status->bpc);
    DEBUG_PRINTF("wpc:            %u\n", status->wpc);
    DEBUG_PRINTF("raw_gma:        %u\n", status->raw_gma);
    DEBUG_PRINTF("lenc:           %u\n", status->lenc);
    DEBUG_PRINTF("hmirror:        %u\n", status->hmirror);
    DEBUG_PRINTF("vflip:          %u\n", status->vflip);
    DEBUG_PRINTF("dcw:            %u\n", status->dcw);
    DEBUG_PRINTF("colorbar:       %u\n", status->colorbar);
  }
};

#endif
